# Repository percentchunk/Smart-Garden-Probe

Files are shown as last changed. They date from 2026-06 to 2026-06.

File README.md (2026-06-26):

# Smart Garden Probe

The Smart Garden Probe is a small plant-monitoring device built around the Seeed Studio XIAO RP2040. It uses a soil sensor and OLED display to show soil moisture, temperature, and whether the plant is in a good range.

## Overview

This project started as a three-key Hackpad, but I wanted it to do something more useful than keyboard shortcuts, and complex enough that it stands on its own.

The device has three buttons, an OLED display, and an I2C soil sensor. The sensor reads soil moisture and temperature, and the screen shows the readings along with a simple status such as Too Dry, Good, or Too Wet.

The firmware also uses plant profiles. Each profile stores the moisture and temperature ranges for a specific plant, you can edit this with the database in the github.

## Features

* Seeed Studio XIAO RP2040
* Three MX-style switches
* SSD1306 I2C OLED
* I2C capacitive soil sensor
* Custom two-layer PCB
* Custom 3D-printed enclosure
* USB-C power
* Plant profile system
* Moisture and temperature shown together
* Gerber, drill, and STEP files included

## Project Views

| Top View | Front View | PCB View |
| --- | --- | --- |
| Top view | Front view | PCB view |

## How It Works

The soil sensor sends moisture and temperature readings to the XIAO RP2040 over I2C.

The firmware compares the readings with the selected plant profile. The OLED then shows the plant name, moisture, temperature, and status.

The three buttons are used to refresh the readings, change the plant profile, and control the display.

## Button Functions

| Button | Function |
| --- | --- |
| SW1 | Refresh the sensor readings |
| SW2 | Change the plant profile |
| SW3 | Turn the display on or off  |

## Hardware

| Part | Details |
| --- | --- |
| Microcontroller | Seeed Studio XIAO RP2040 |
| Display | 128×64 SSD1306 I2C OLED |
| Sensor | I2C soil moisture and temperature sensor |
| Inputs | Three MX-style switches |
| Power | USB-C |
| PCB | Custom two-layer KiCad PCB |
| Enclosure | 3D-printed top and bottom case |

## PCB

The PCB was designed in KiCad and is about 62.5 mm by 62.5 mm.

It includes:

* The XIAO RP2040
* Three switch footprints
* OLED header
* Soil sensor header
* Four 2.5 mm mounting holes

## Cad

The pad was designed in Onshape.

I added the PCB model to the CAD assembly so I could check the mounting holes, headers, USB-C port, switches, OLED, and cable opening.

The mounting holes and clearances were corrected after checking the PCB inside the case.

## Firmware

The firmware is designed to:

* Read the soil sensor
* Show moisture and temperature
* Compare readings with plant profiles
* Show simple status messages
* Change profiles with SW2
* Refresh readings with SW1
* Control the display with SW3

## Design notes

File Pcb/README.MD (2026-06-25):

PCB Files
This folder contains the KiCad PCB design files and manufacturing outputs for the Smart Garden Probe Hackpad.

The PCB is a custom 2-layer board built around the Seeed XIAO RP2040. It includes three MX-style switch inputs, an OLED I2C header, and an I2C soil sensor header.

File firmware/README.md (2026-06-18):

# Firmware

This folder contains the firmware for the Smart Garden Probe Hackpad.

The firmware will read the soil sensor over I2C, display soil moisture and temperature on the OLED, and handle the three macropad buttons.

Read Soil moisture and temps
Display both values
Use Sw1 to refresh
Use Sw2 to cycle plant profiles
Use SW3 for power options

## Test File

`test_profiles.py` is a simple demo script that tests the plant profile system without needing the physical hardware connected. It uses sample moisture and temperature values and shows whether each saved plant profile would read as too dry, too wet, too cold, too hot, or good.

**RESULT OF TEST FILE**



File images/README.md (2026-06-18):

# Images

This README contains screenshots, renders, and project images used in the main README and submission.Screenshot 2026-06-17 at 3 52 02 PM (2)
Screenshot 2026-06-18 at 8 58 37 AM
Screenshot 2026-06-18 at 10 25 15 AM (2)
Screenshot 2026-06-17 at 11 50 49 AM (2) 2
Screenshot 2026-06-17 at 11 51 11 AM 2
Screenshot 2026-06-17 at 11 51 18 AM 2
Screenshot 2026-06-17 at 11 44 25 AM 2
Screenshot 2026-06-17 at 11 44 27 AM 2

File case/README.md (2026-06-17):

# Case Files

This folder contains the CAD files for the 3D-printed enclosure.

The case is a sandwich-style design with a top plate and bottom shell. It includes switch cutouts, an OLED window, a USB-C cutout for the XIAO RP2040, and space for the soil sensor cable.

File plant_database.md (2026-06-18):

# Plant profile Database

This file will contain exampel plant profiles that users can copy into the firmware

The smart garden probe hackpad is planned to support up to 5 saved plant profuels at a time.  
Each profile will include 
1.Plant name
2. target soil misture range
3.target temperature range
4. status labels such as Too Dry, Good, Or too wet

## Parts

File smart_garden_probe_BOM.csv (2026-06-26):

Part | Quantity | Price (USD) | Product Link | Purpose
Seeed Studio XIAO RP2040 | 1 | 3.79 | https://www.seeedstudio.com/XIAO-RP2040-v1-0-p-5026.html | Main microcontroller
Adafruit STEMMA Soil Sensor | 1 | 7.50 | https://www.digikey.com/en/products/detail/adafruit-industries-llc/4026/9745252 | Measures soil moisture and local temperature
0.96-inch SSD1306 I2C OLED | 1 | 6.89 | https://shillehtek.com/products/0-96-i2c-blue-oled-display-module-4-pin-ssd1306 | Displays the selected plant, sensor readings, and status
Custom 2-layer PCB | 1 order / 5 boards | 2.00 | https://jlcpcb.com/ | Connects the XIAO, switches, OLED, and sensor
Gateron MX switches | 1 pack / 20 switches | 2.99 | https://www.ebay.com/itm/137016595098 | Three switches are used for device controls
Blank 1U keycaps | 1 pack / 10 keycaps | 9.99 | https://www.walmart.com/ip/Uxcell-1U-Blank-Keycaps-PBT-Universal-Keyboard-Replacement-Accessories-for-MX-Mechanical-Keyboard-Black-10-Pack/1837060092 | Covers the three mechanical switches
M3 heat-set inserts | 4 | 1.79 | https://partsbuilt.com/m3-heat-set-thread-insert-5mm-long-4-pack/ | Provides threaded mounting points in the enclosure
M3 x 8 mm screws | 1 pack / 20 screws | 1.95 | https://bc-robotics.com/shop/m3-x-8mm-phillips-20-pack/ | Secures the enclosure
2.54 mm breakaway headers | 1 strip | 1.00 | https://www.pololu.com/product/2664 | Connects the XIAO, OLED, and soil sensor
3D-printed enclosure | 1 set | 1.50 | Printed from included STEP files | Holds and protects the electronics
Hookup wire and solder | As needed | 1.00 | Already available | Used for sensor wiring and assembly
Total |  | 40.40

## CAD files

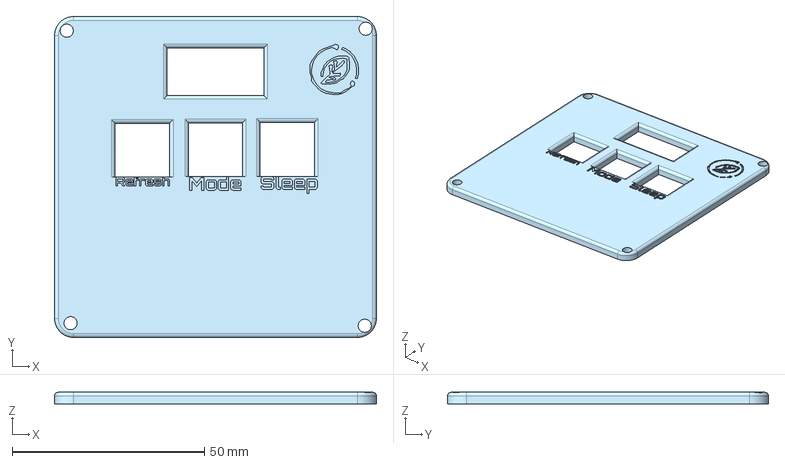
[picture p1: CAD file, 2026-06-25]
case/Bottom Case.step
83.7 x 83.5 x 3.00 mm

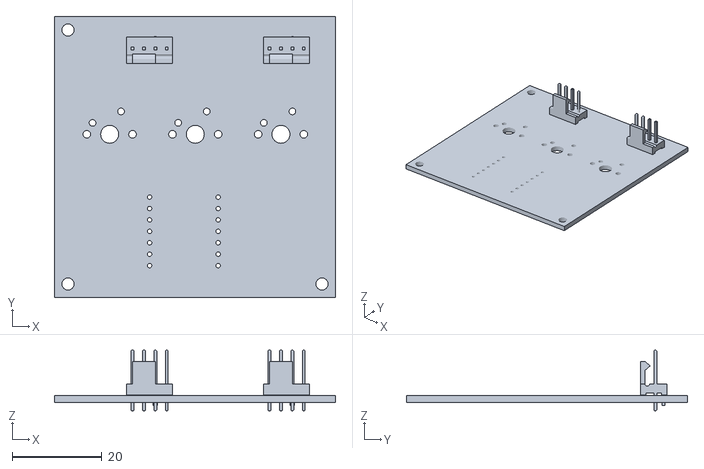
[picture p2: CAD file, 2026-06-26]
Pcb/HackPacOG.stl
62.5 x 62.5 x 13.5

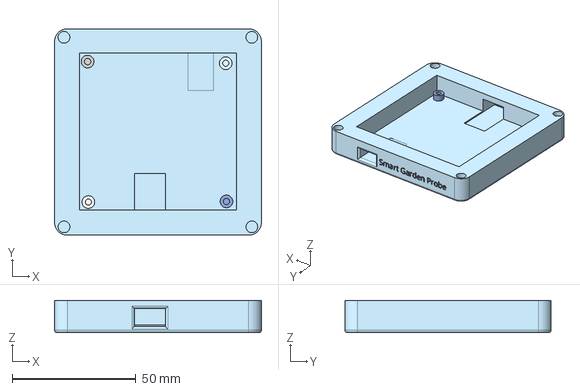
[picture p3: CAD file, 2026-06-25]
case/Top Case.step
83.6 x 83.3 x 13.0 mm

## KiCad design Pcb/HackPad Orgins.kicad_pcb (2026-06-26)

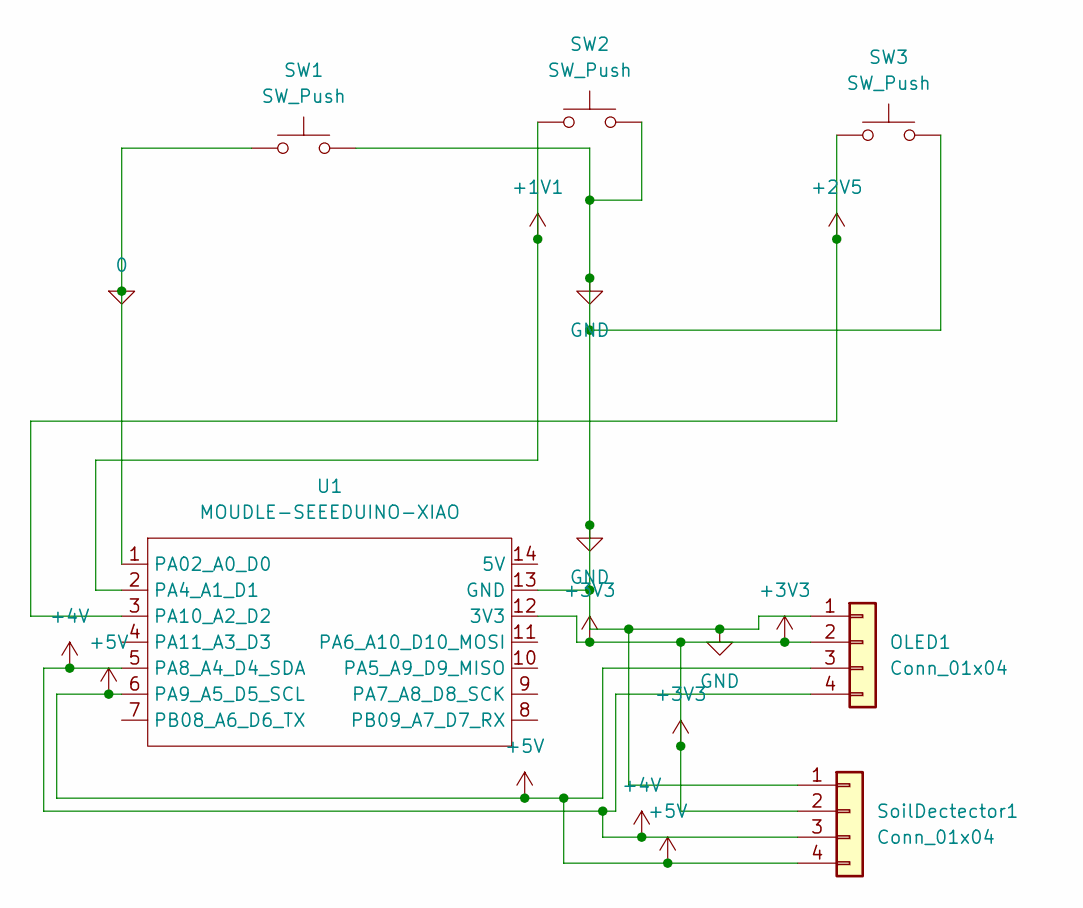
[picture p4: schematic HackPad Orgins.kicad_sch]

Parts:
OLED1: Conn_01x04; FanPinHeader_1x04_P2.54mm_Vertical
SW1, SW2, SW3: SW_Push; SW_Cherry_MX_1.00u_PCB
SoilDectector1: Conn_01x04; FanPinHeader_1x04_P2.54mm_Vertical
U1: MOUDLE-SEEEDUINO-XIAO; XIAO-Generic-Hybrid-14P-2.54-21X17.8MM

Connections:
0: SW1.1, U1.1 (PA02_A0_D0)
+1V1: SW2.1, U1.2 (PA4_A1_D1)
+2V5: SW3.1, U1.3 (PA10_A2_D2)
+3V3: OLED1.2, SoilDectector1.2, U1.12 (3V3)
+4V: OLED1.4, SoilDectector1.3, U1.5 (PA8_A4_D4_SDA)
+5V: OLED1.3, SoilDectector1.4, U1.6 (PA9_A5_D5_SCL)
GND: OLED1.1, SW1.2, SW2.2, SW3.2, SoilDectector1.1, U1.13 (GND)

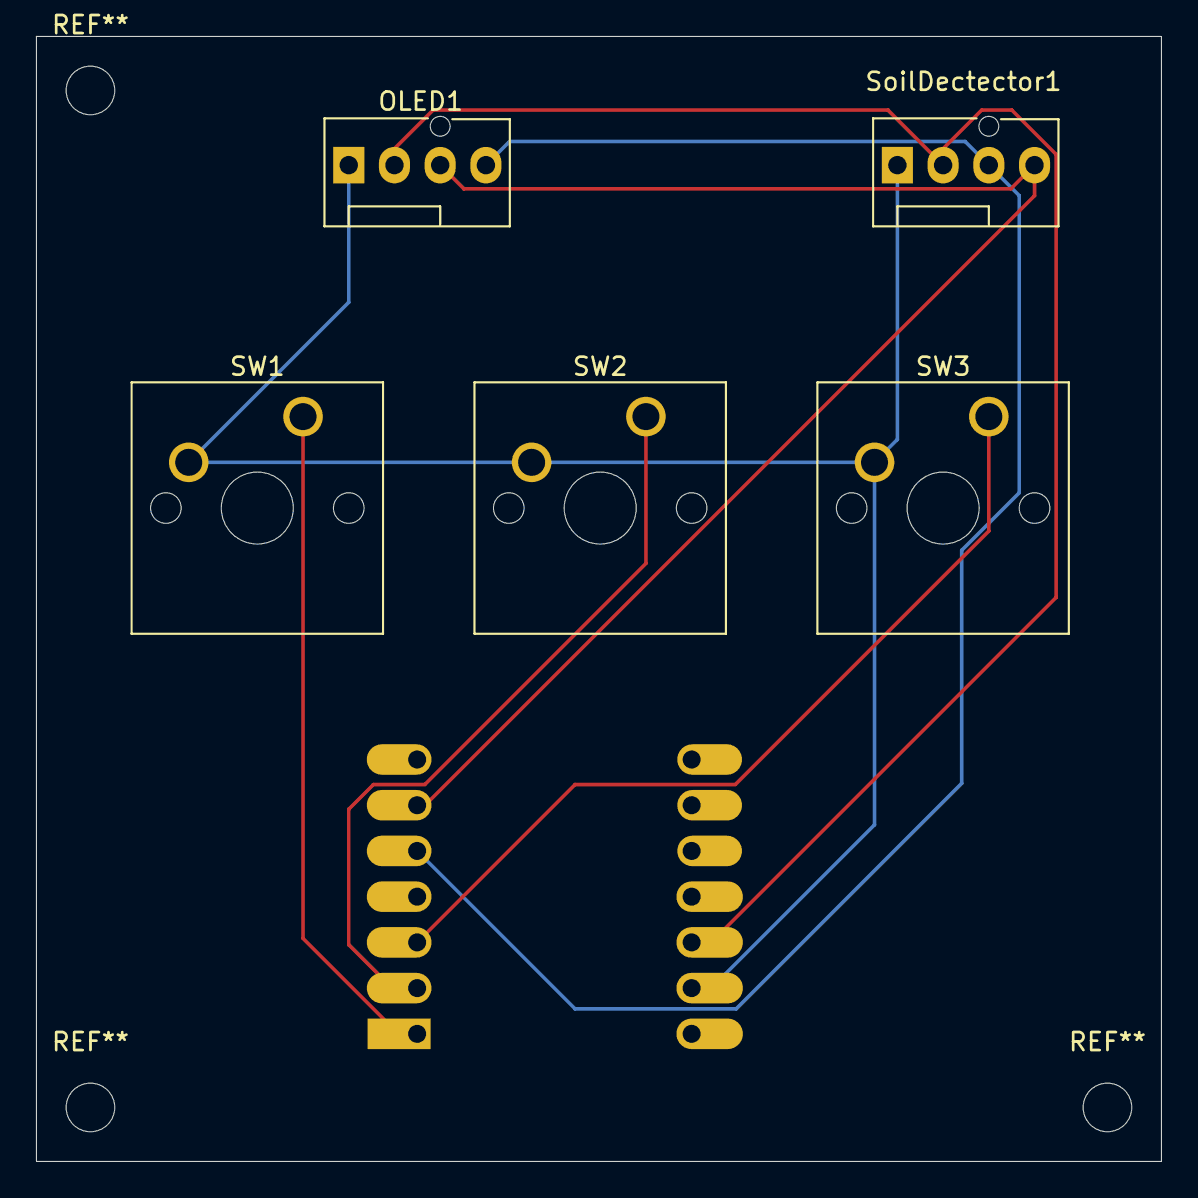
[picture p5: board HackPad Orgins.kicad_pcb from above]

Board: 2 copper layers, 62.5 x 62.5 mm, 6 parts (1 on the bottom side), 7 nets.

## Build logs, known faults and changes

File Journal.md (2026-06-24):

# Smart Garden Probe Project Journal

## Current Total Time

**6 hours completed**

Assembly and physical testing will be added after the PCB and components arrive.

## Project Planning — 30 minutes

I planned the Smart Garden Probe as a three-button device that also works as a standalone plant monitor. I decided to use a XIAO RP2040, OLED display, capacitive soil sensor, custom PCB, and 3D-printed enclosure.

## Schematic Design — 1 hour

I created the schematic in KiCad and connected the three switches to the XIAO GPIO pins. I also connected the OLED and soil sensor to the shared I2C bus and added headers for both devices.

## PCB Design — 1 hour 30 minutes

I designed and routed a custom two-layer PCB. I placed the XIAO, three MX switches, OLED header, soil-sensor header, and mounting holes, then exported the Gerber and drill files.
Screenshot 2026-06-17 at 11 50 49 AM (2) 2
Screenshot 2026-06-17 at 11 51 11 AM 2

## Enclosure CAD — 1 hour 15 minutes

I designed the top plate and bottom enclosure in Onshape. The case includes switch openings, an OLED window, USB-C access, a soil-sensor cable opening, PCB supports, and screw mounting points.
Screenshot 2026-06-17 at 11 44 27 AM 2

## Firmware and Plant Profiles — 1 hour 15 minutes

I created the firmware structure for the buttons, OLED, soil sensor, automatic updates, and plant-profile cycling. I also created moisture and temperature status logic and a test script that can run before the hardware arrives.
610020152-e79e22c7-d8fa-47d8-90f6-0c1a537301cb

## Repository Documentation — 30 minutes

I organized the GitHub repository and added the README, BOM, firmware files, plant database, PCB files, Gerbers, STEP files, and project renders.

## Future Work

The following work is not included in the current six-hour total as it has not been started yet:

* PCB assembly
* Soldering
* Enclosure assembly
* OLED and sensor testing
* Soil-sensor calibration
* Final plant demonstration

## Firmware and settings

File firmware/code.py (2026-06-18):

#Smart Garden Probe Hackapad 
#Board to be used is the Seeed Studio XIAO RP2040
#Post Conditions
# Use three buttons for refresh, mode, and sleep

#read the soil sensor
#display soil moisture and local temperature on OLED
#sw1 refreshes the reading
#sw2 cycles plant proiles 
#sw3 controls sleepdisplay behavior
import time
import board
import digitalio
import busio 

from plants import PLANTS

#OlED imports 
import displayio
import terminalio
from adafruit_display_text import label
from i2cdisplaybus import I2CDisplayBus
import adafruit_displayio_ssd1306

#Soil Sensor imports
from adafruit_seesaw.seesaw import Seesaw

MAX_PLANTS = 5 
active_plants=PLANTS[:MAX_PLANTS]
current_plant_index=0
display_enabled = True

#Button Setup
refresh_button = digitalio.DigitalInOut(board.D0)
refresh_button.direction = digitalio.Direction.INPUT
refresh_button.pull = digitalio.Pull.UP

mode_button = digitalio.DigitalInOut(board.D1)
mode_button.direction = digitalio.Direction.INPUT
mode_button.pull = digitalio.Pull.UP

sleep_button = digitalio.DigitalInOut(board.D2)
sleep_button.direction = digitalio.Direction.INPUT
sleep_button.pull = digitalio.Pull.UP

#I2C Set up
i2c = busio.I2C(board.SCL, board.SDA)
soil_sensor = Seesaw(i2c, addr=0x36)

#OlED Setup

displayio.release_displays()

display_bus = I2CDisplayBus(i2c,device_address=0X3C)

WIDTH=128
HEIGHT = 64
display = adafruit_displayio_ssd1306.SSD1306(
    display_bus,
    width=WIDTH,
    height=HEIGHT,
)
#sonion tis is so much codeeeee
screen = displayio.Group()
display.root_group = screen

line1 = label.Label(terminalio.FONT,text="", x=0,y=10)
line2 = label.Label(terminalio.FONT,text="", x=0, y=25)
line3 = label.Label(terminalio.FONT, text="", x=0, y=40)
line4 = label.Label(terminalio.FONT,text="", x=0, y=55)

screen.append(line1)
screen.append(line2)
screen.append(line3)
screen.append(line4)

#plant logic 

def get_current_plant():
    return active_plants[current_plant_index]

def check_range(value,minimum, maximum):
    if value < minimum:
        return "Too Low"
    if value > maximum:
        return "Too High"
    return "Good"

def check_moisture(moisture_value,plant):
    if moisture_value < plant["moisture_min"]:
        return "Too Dry"
    if moisture_value > plant["moisture_max"]:
        return "Too Wet"
    return "Good"

def check_temperature(temp_c, plant):
    return check_range(temp_c, plant["temp_min_c"], plant["temp_max_c"])

def cycle_plant():
    global current_plant_index
    current_plant_index = (current_plant_index + 1) % len(active_plants)
    return get_current_plant()

def read_sensor():
    moisture = soil_sensor.moisture_read()
    temperature_c = soil_sensor.get_temp()
    return moisture, temperature_c

def update_display(moisture,temperature_c):
    plant = get_current_plant()
    moisture_status = check_moisture(moisture,plant)
    temp_status = check_temperature(temperature_c,plant)

    line1.text = plant["name"]
    line2.text = "M: " +str(moisture) + " " + moisture_status
    line3.text = "T: " + str(temperature_c)+ "C " + temp_status
    line4.text = "SW2 changes plant"
    
    print("Plant:",plant["name"])
    print("Moisture:",moisture,moisture_status)
    print("Temperature:", temperature_c,"C",temp_status)
    print("--------------")

def show_sleep_screen():
    line1.text = "Smart Garden"
    line2.text = "Display off"
    line3.text = "Press SW3"
    line4.text = "to wake"

#placeholder sensor values until the hardware is added
last_refresh_state = True
last_mode_state = True
last_sleep_state = True

last_update_time = 0
update_interval = 10

moisture,temperature_c = read_sensor()
update_display(moisture, temperature_c)

while True:
    refresh_state = refresh_button.value
    mode_state = mode_button.value
    sleep_state = sleep_button.value

    if last_refresh_state and not refresh_state:
        if display_enabled:
            moisture, temperature_c = read_sensor()
            update_display(moisture,temperature_c)
    
    if last_mode_state and not mode_state:
        if display_enabled:
            cycle_plant()
            moisture, temperature_c = read_sensor()
            update_display(moisture, temperature_c)
    
    if last_sleep_state and not sleep_state:
        display_enabled = not display_enabled

        if display_enabled:
            moisture,temperature_c = read_sensor()
            update_display(moisture, temperature_c)
        else: 
            show_sleep_screen()

    if display_enabled and time.monotonic() - last_update_time > update_interval:
        moisture,temperature_c = read_sensor()
        update_display(moisture, temperature_c)
        last_update_time = time.monotonic()

    last_refresh_state = refresh_state
    last_mode_state = mode_state
    last_sleep_state = sleep_state

    time.sleep(0.05)    

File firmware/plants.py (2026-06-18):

#plant profiels for the Smart Garden probe
#Users can copy plant profiles from plant_Database.md into thisl ist

# keep this list to 5 plants or fewer for optimal usage

PLANTS = [
    {
        "name":"Basil",
        "moisture_min" : 500,
        "moisture_max" : 800,
        "temp_min_c": 18,
        "temp_max_c": 30,
                    },
    {
        "name":"Snake Plant",
        "moisture_min":250,
        "moisture_max":500,
        "temp_min_c":18,
        "temp_max_c":29,
    },
    {
        "name":"Pothos",
        "moisture_min":400,
        "moisture_max":700,
        "temp_min_c":18,
        "temp_max_c":30,
    },
]
